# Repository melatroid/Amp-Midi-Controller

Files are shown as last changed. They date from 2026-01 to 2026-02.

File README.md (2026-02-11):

# Amp-MIDI-Controller

Files & Flashing Tool for 2040 Zero here...
<div align="left">
  <a href="https://www.nexosoft-engineering.de/amp/index.html">Full Version & Flashing Click here...</a>
</div

Amp-MIDI-Controller is a DIY build guide plus software for a flexible control module that lets you connect any MIDI foot controller to common guitar amp models and/or other MIDI interfaces using a simple configuration.

A built-in Teach Mode allows you to quickly “learn” and map specific MIDI signals, route them to different targets, and even create chained actions (multiple commands triggered by a single footswitch press).

Why this exists

Many tube amp manufacturers do not provide a way to switch the effects loop (Send/Return) via foot control. In practice, that often forces guitarists into the classic “pedalboard dance” when switching channels and toggling the loop separately.

Amp-MIDI-Controller solves this by allowing you to logically link amp channels to the effects loop, so your MIDI foot controller can change channels and switch the loop in a coordinated, predictable way.

Expandable design

At the highest configuration level, the module can even extend an amp to support two independent effects loops, adding more flexibility for channel-based routing and setups.

Display-driven workflow

An integrated display lets you select amp models and channels and makes it easy to pair the system with virtually any MIDI foot controller.

# Key Features

1. Works with any MIDI foot controller
2. Simple configuration for amps and other MIDI devices
3. Teach Mode for learning/mapping MIDI messages
4. MIDI routing & distribution across multiple outputs

### Status
- 1.) Hardware (✅)
- 2.) Hardware Test (✅)
- 3.) Software (✅)
- 4.) 3D-Print-Body (✅)
- 5.) Payment Plattform (✅)

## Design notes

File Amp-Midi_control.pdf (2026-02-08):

# AMP-Midi-Controller

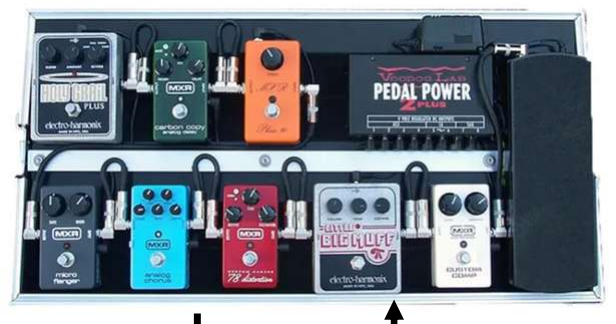
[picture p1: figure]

Works with all Amps with a real Midi Support. nexosoftengineering@gmail.com

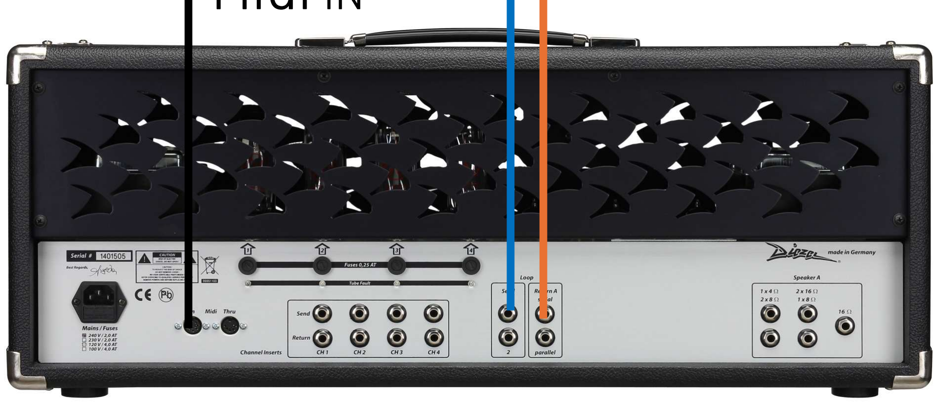
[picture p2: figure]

# Midi IN

# Midi OUT Midi IN

From FX | To FX
Send | Return

# From send To Return

Midi-maps of this amps are includet: •ENGL: • | Savage 120 Mark II • | Savage 60 Mark II • | Ironball SE
- | Powerball II • | Special Edition E670 / E670FE
- | Invader II • | Invader 150 (E646) •Diezel:• | VH4 / VH4S
- | Herbert (MK I & II) •Mesa/Boogie: • | JP-2C (John Petrucci Signature) •Hughes & Kettner: • | GrandMeister Deluxe 40
•Revv: • | Generator 120 Mark III • | D20 / D20+
•EVH: • | 5150 III (50W EL34 / Stealth) •Marshall: • | JVM410 (via MIDI Learn Mapping) •Victory:• | V4 The Kraken
•Blackstar: • | | Series One 100 / 200

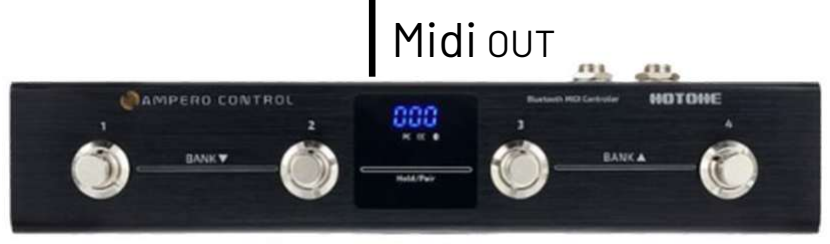
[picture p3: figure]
Midi OUT

•Modeler (Basis-Maps): • | | Fractal Audio Axe-FX III / FM9
- | Line 6 Helix Rack / Floor • | Headrush Pedalboard / Gigboard

# Hardware Parts

## LM2596 x1 Alternativ: MP1584EN

## DC Input-Jacket

## Raspberry Pi 2040 Zero x1

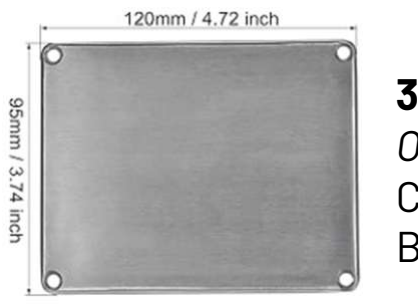
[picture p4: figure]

## 3D Print

OR

## CASE / BOX x1

## 6,35mm x4-6

## Midi 5-POL –Jacket

x2-3

SPST Momentary,
NO
x1

## SSD1306 OR SSD1315 O-LED I²C !!!

SPST Momentary,
NO
x1

# Electronic Parts

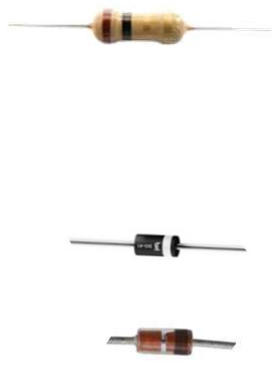
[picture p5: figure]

1N4001 x1

## 1 k Ω 0 4x

220Ω 4x

## 1 MΩ 4x

## 4,7 kΩ 1x 47 kΩ 1x

100 nF

1N4148 x1

100 uF

### 47 uF

10-22 uF

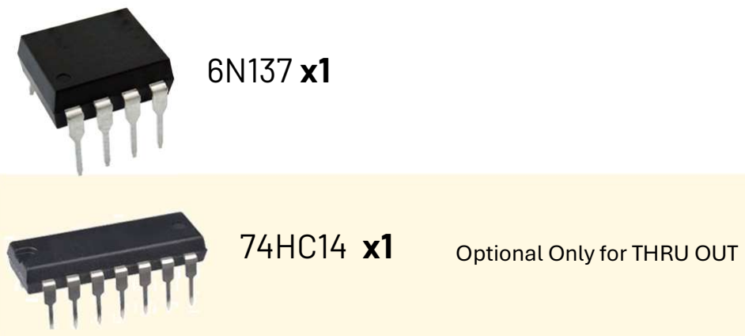
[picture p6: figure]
Optional Only for THRU OUT
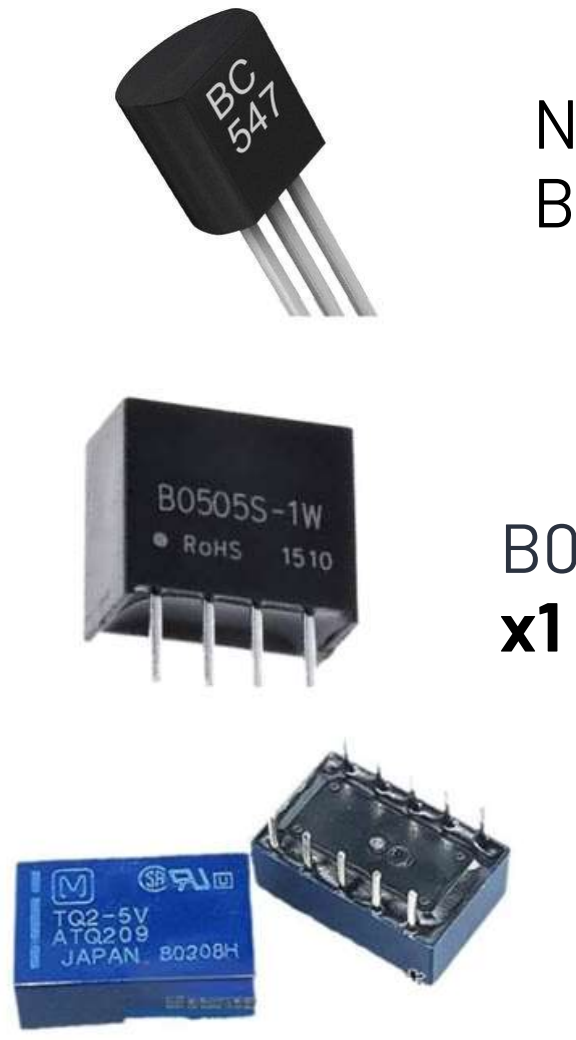
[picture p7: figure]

## NPN BC547 x3

## B0505S-1W

## TQ2-L2-5V

x1-2

## IC Socket, 8 , 14 ,10 PINS

## Electro Cookie PCB

# Tools

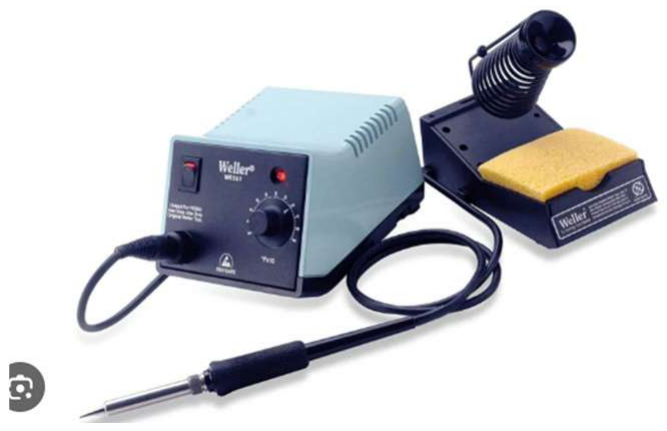
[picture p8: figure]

## Solder Station

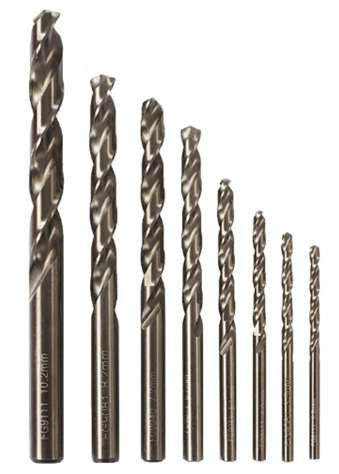
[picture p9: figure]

## Dill Set

## 3D Printer (optional)

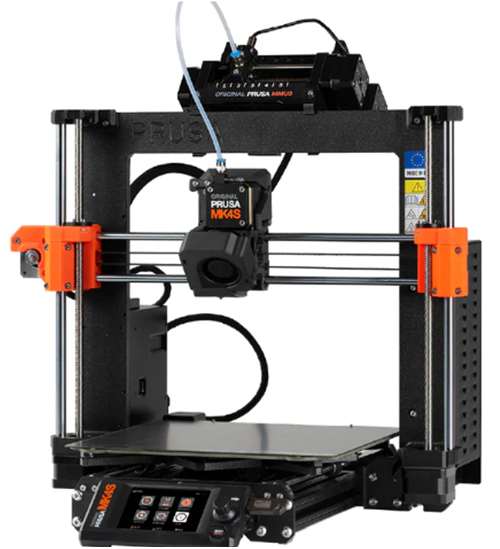
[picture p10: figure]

## Hot Glue

## Copper Tape

## EMV-Shield Inside Body

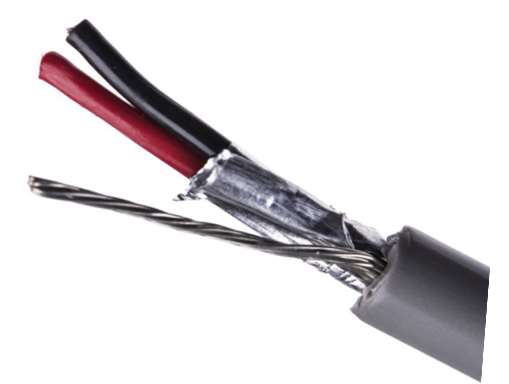
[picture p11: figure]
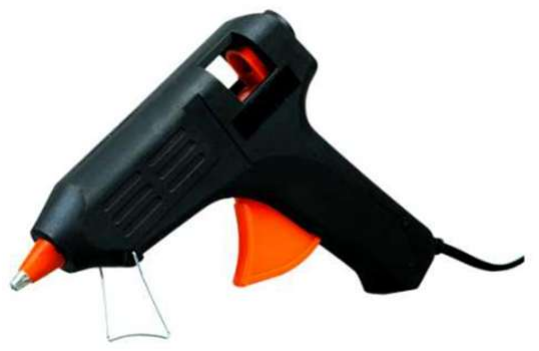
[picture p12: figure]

## Audio Wire

# Order List

# https://www.amazon.de/dp/B0D3D5YB7G

# https://www.amazon.de/dp/B0DGKQH5QF

# https://www.amazon.de/dp/B0CPSKSFZM

# https://www.amazon.de/dp/B0D3DG8M6J

# https://www.amazon.de/dp/B0DXDVL1PF

# https://www.amazon.de/dp/B0DRCSM7D1 https://www.amazon.de/dp/B0D1Q6P6WK

# https://www.amazon.de/dp/B0BN1VYW3X

# https://www.amazon.de/dp/B0BN1NKWYZ

# https://www.amazon.de/dp/B0CTM58CLJ https://www.amazon.de/dp/B08HQ7K6M7

# Body - 1 FX

# M3 x 4 x 5 mm

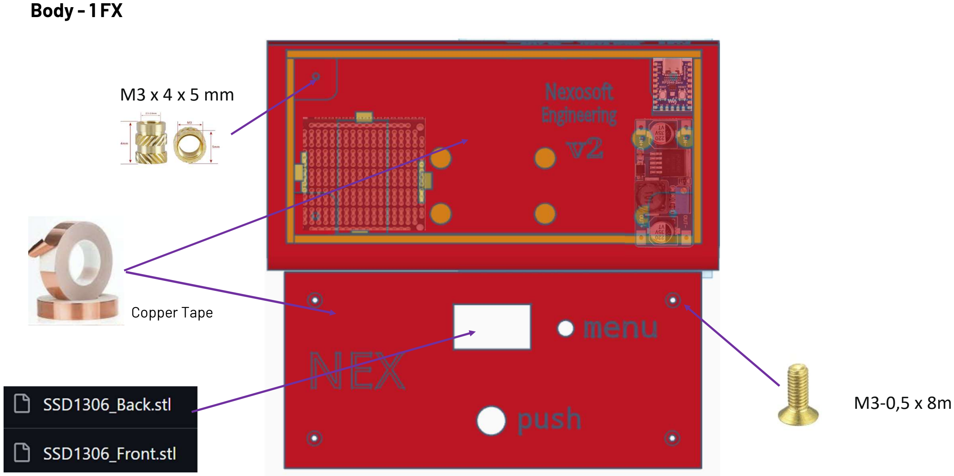
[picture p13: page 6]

# M3-0,5 x 8m

## Copper Tape

# DC/DC Converter

LM2596

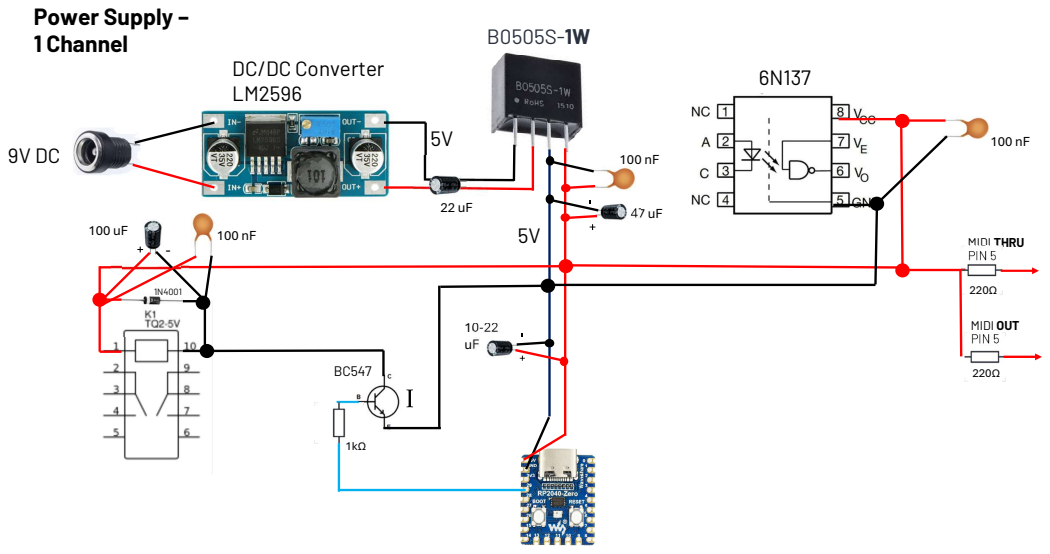
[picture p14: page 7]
Power Supply –; 1 Channel; MIDI THRU PIN 5; - MIDI OUT; PIN 5

# DC/DC Converter

LM2596

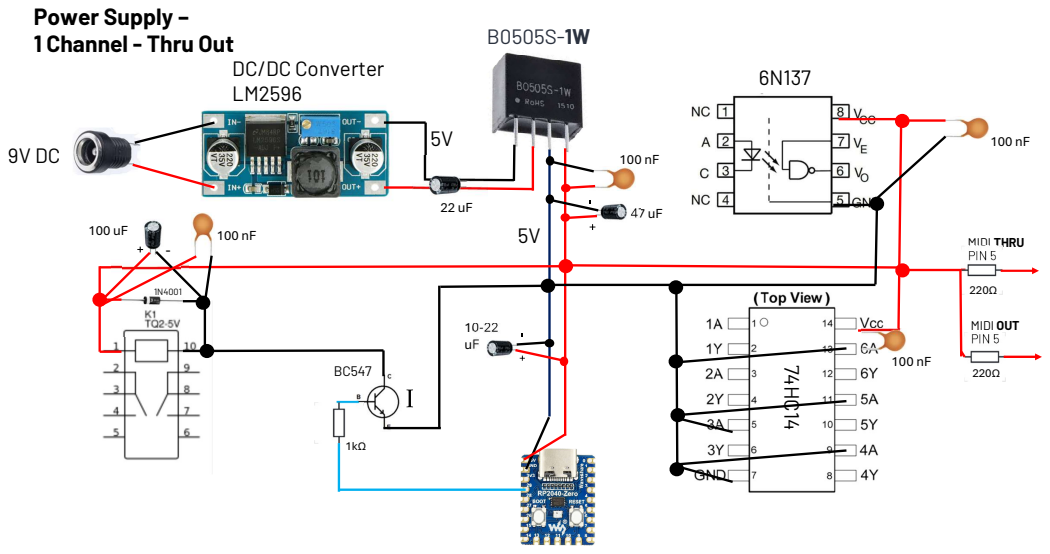
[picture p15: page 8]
Power Supply –; 1 Channel - Thru Out; MIDI THRU PIN 5; - MIDI OUT; PIN 5

# DC/DC Converter

LM2596

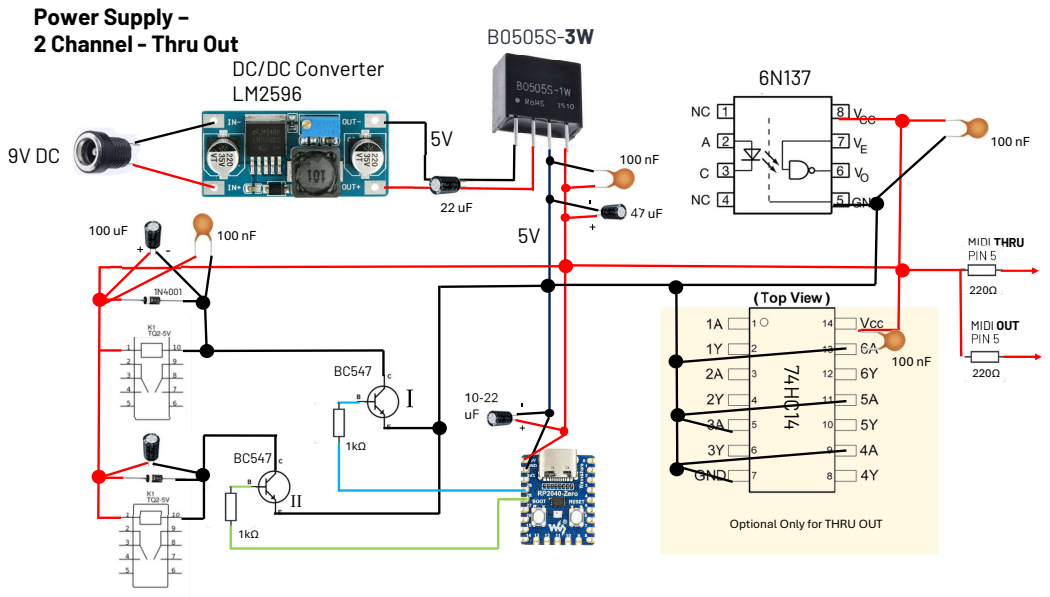
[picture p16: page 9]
Power Supply –; 2 Channel - Thru Out; MIDI THRU PIN 5; - MIDI OUT; PIN 5

Optional Only for THRU OUT

# Midi IN/OUT

# MIDI

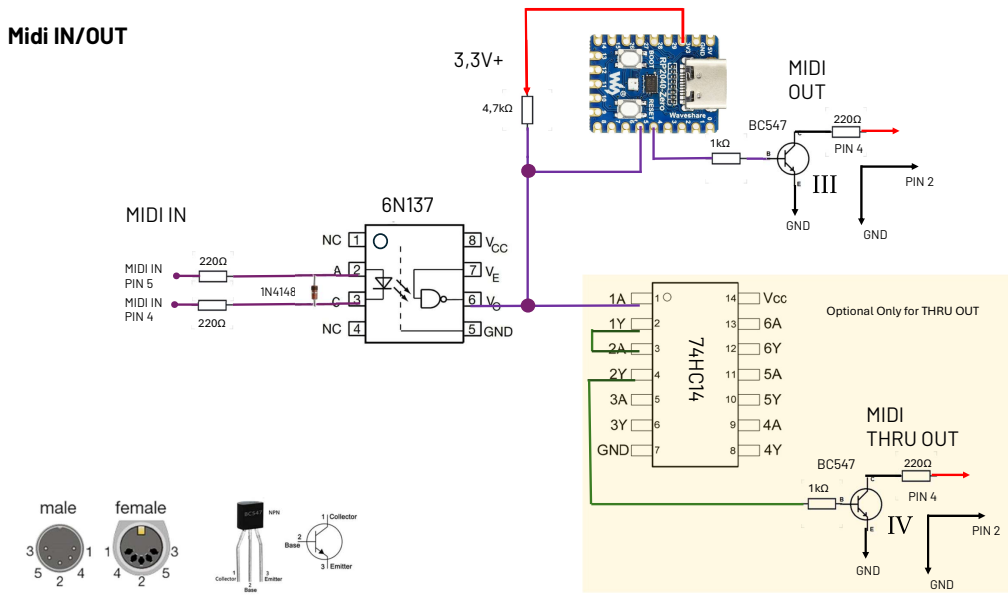
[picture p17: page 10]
MIDI IN PIN 4; MIDI IN PIN 5; PIN 4; GND; MIDI IN; MIDI; THRU OUT ⁷⁴HC14; OUT; PIN 2

Optional Only for THRU OUT

# Display

SDA

SCL

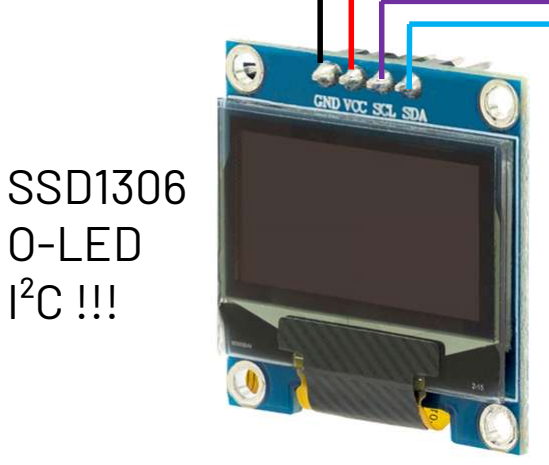
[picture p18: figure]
SSD1306 O-LED I²C !!!

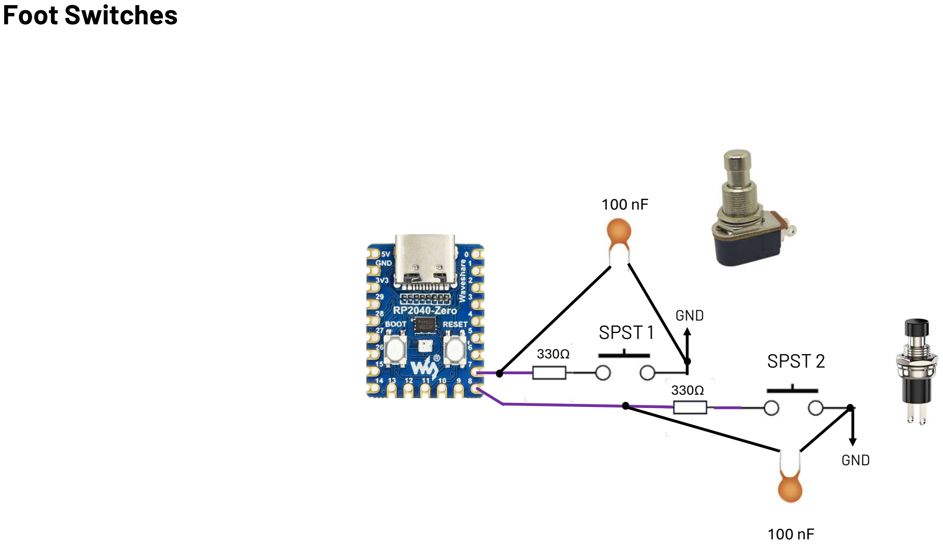
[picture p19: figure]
Foot Switches; SPST 1; SPST 2; GND

# Loop

FX

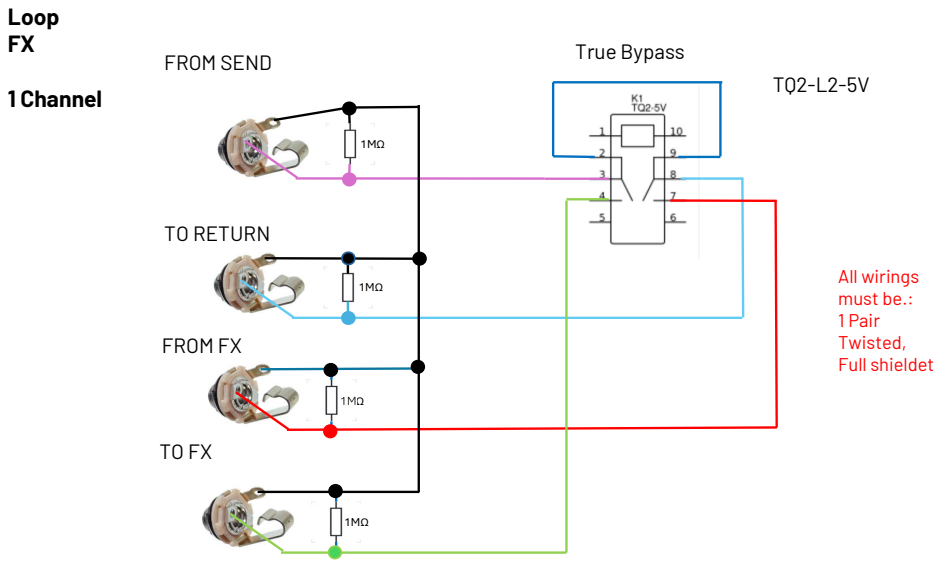
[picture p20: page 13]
1 Channel; FROM FX; FROM SEND; TO RETURN; True Bypass; All wirings must be.: 1 Pair Twisted, Full shieldet

# Loop

FX

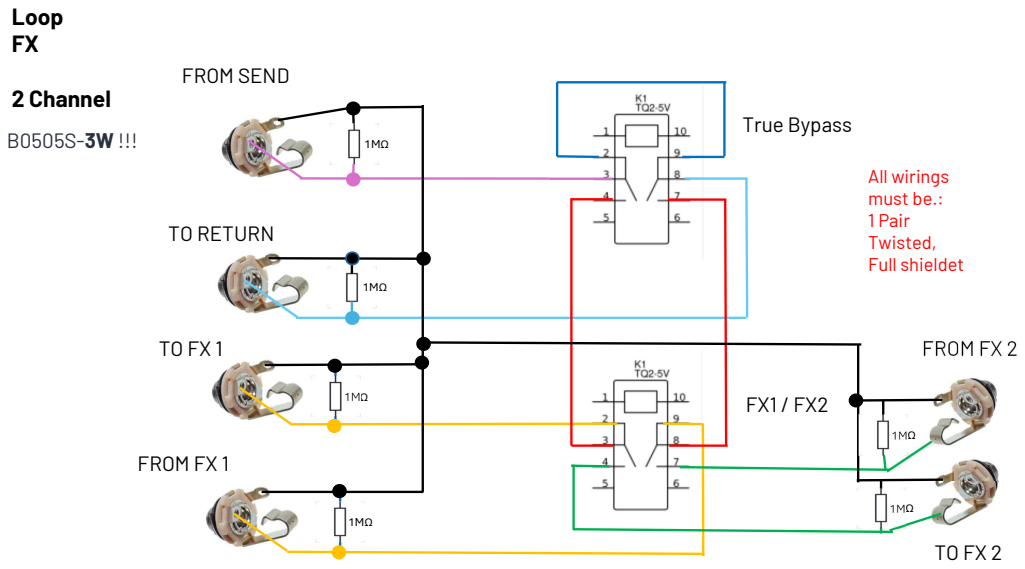
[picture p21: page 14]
2 Channel; FROM FX 1; True Bypass; TO RETURN; FROM FX 2; FROM SEND; All wirings must be.: 1 Pair Twisted, Full shieldet

# Images

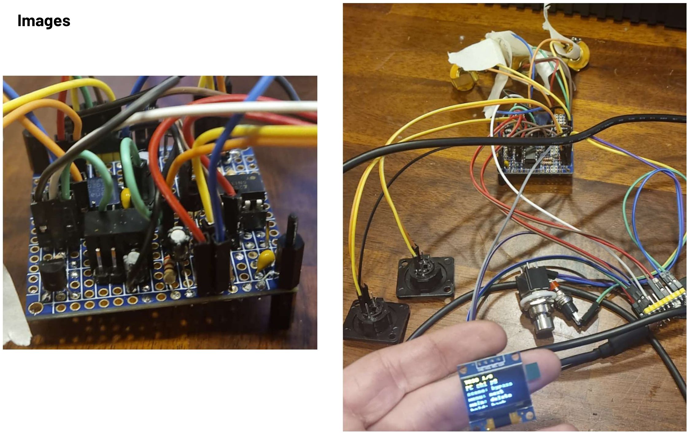
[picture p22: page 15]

# Images

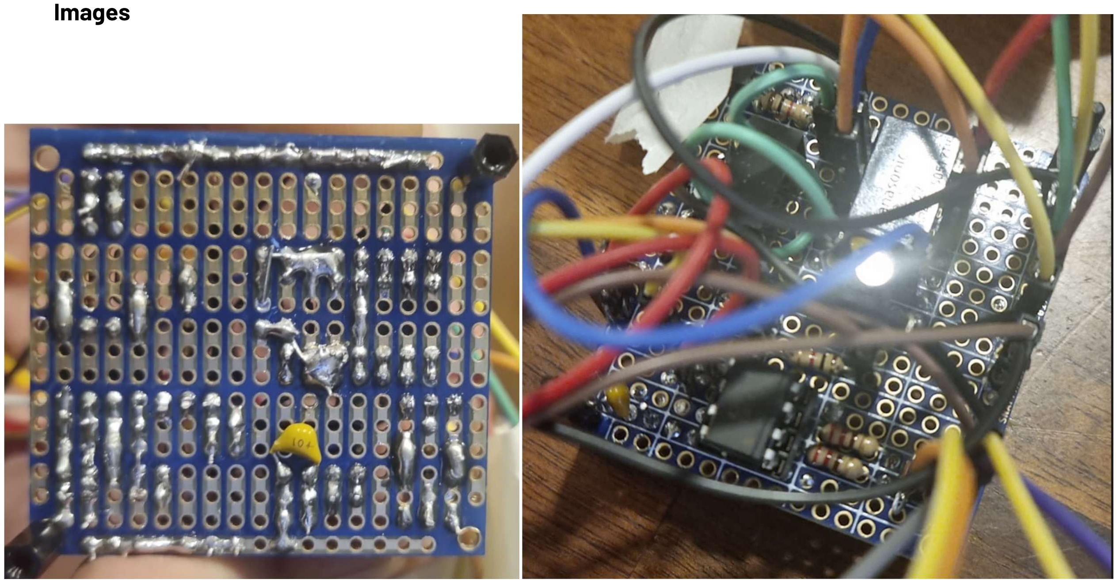
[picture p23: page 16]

# Images

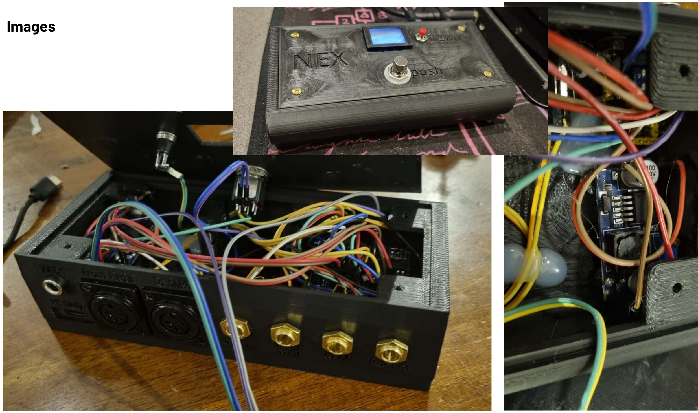
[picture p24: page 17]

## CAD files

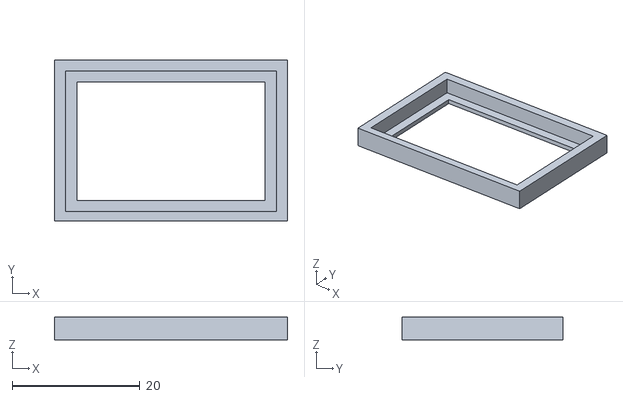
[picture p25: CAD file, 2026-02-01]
SSD1306_Front.stl
36.5 x 25.2 x 3.60

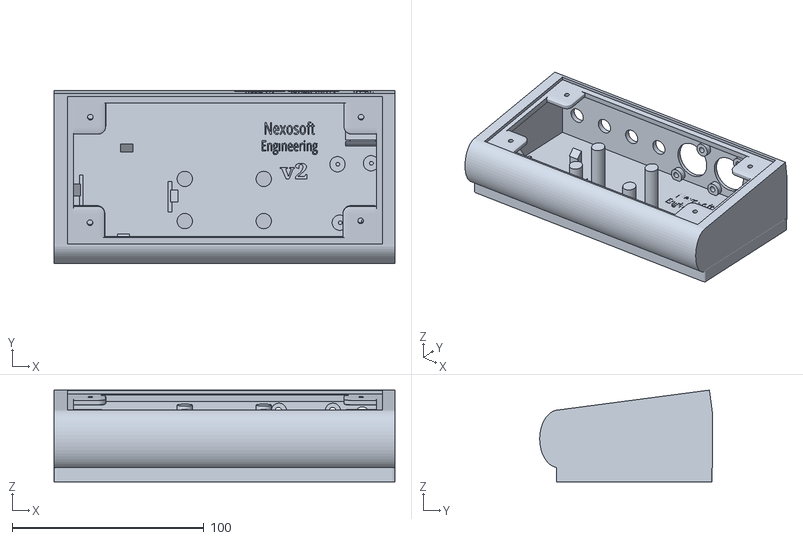
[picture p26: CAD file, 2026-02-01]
Amp Midi Switch 1 FX - FOOTS.stl
177.9 x 90.1 x 47.9

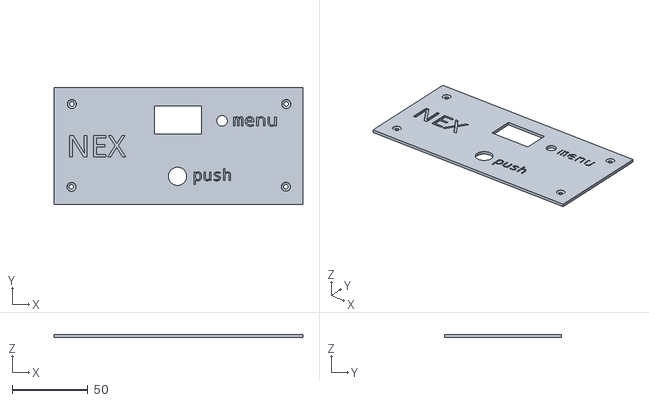
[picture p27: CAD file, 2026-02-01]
Amp Midi Switch 1 FX - TOP.stl
164.1 x 77.1 x 2.02

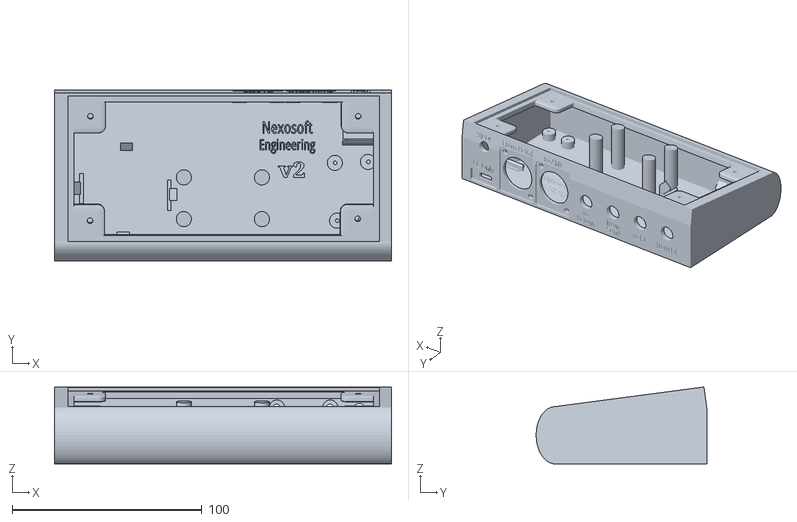
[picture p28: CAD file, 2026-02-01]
Amp Midi Switch 1 FX - DUAL LOOK.stl
177.8 x 90.1 x 40.6

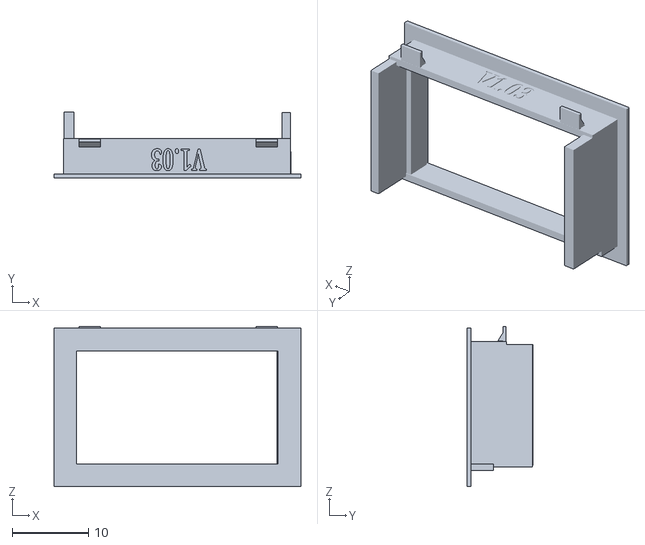
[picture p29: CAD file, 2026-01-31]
SSD1306_Back.stl
32.3 x 8.65 x 21.0

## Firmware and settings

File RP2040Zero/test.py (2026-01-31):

from machine import Pin, UART, I2C
import time
from ssd1306 import SSD1306

# ---------- Pins ----------
PIN_RELAY     = 29
PIN_RELAY2    = 28
PIN_BTN_MAIN  = 7
PIN_BTN_MENU  = 8
MIDI_IN_PIN   = 5
MIDI_OUT_PIN  = 4

DEBOUNCE_MS = 30

# ---------- OLED (SSD1306/SSD1315) ----------
OLED_SDA = 0
OLED_SCL = 1
OLED_WIDTH = 128
OLED_HEIGHT = 64
OLED_ADDR = 0x3C
OLED_UPDATE_MS = 250

oled = None
last_oled_update = time.ticks_ms()

def oled_init():
    """OLED initialisieren und kurzen Test anzeigen."""
    i2c = I2C(0, sda=Pin(OLED_SDA), scl=Pin(OLED_SCL), freq=400000)
    display = SSD1306(OLED_WIDTH, OLED_HEIGHT, i2c, addr=OLED_ADDR)
    display.fill(0)
    display.text("OLED TEST", 0, 0, 1)
    display.text("SSD1306 OK", 0, 12, 1)
    display.rect(0, 28, 127, 35, 1)
    display.text("AMP TEST", 20, 40, 1)
    display.show()
    return display

def oled_update(display, relay_on, relay2_on, main_pressed, menu_pressed):
    """Kurzer Status-Screen, um OLED im Lauf zu testen."""
    display.fill(0)
    display.text("OLED STATUS", 0, 0, 1)
    display.text("Relay1: %s" % ("ON" if relay_on else "OFF"), 0, 12, 1)
    display.text("Relay2: %s" % ("ON" if relay2_on else "OFF"), 0, 24, 1)
    display.text("Main : %s" % ("DOWN" if main_pressed else "UP"), 0, 36, 1)
    display.text("Menu : %s" % ("DOWN" if menu_pressed else "UP"), 0, 48, 1)
    display.show()

# ---------- Relais & Taster ----------
relay = Pin(PIN_RELAY, Pin.OUT, value=0)
relay2 = Pin(PIN_RELAY2, Pin.OUT, value=0)

# Relais-Zustände in Variablen halten
relay_state = 0
relay.value(relay_state)

relay2_state = 0
relay2.value(relay2_state)

btn_main = Pin(PIN_BTN_MAIN, Pin.IN, Pin.PULL_UP)
btn_menu = Pin(PIN_BTN_MENU, Pin.IN, Pin.PULL_UP)

last_main_change  = time.ticks_ms()
last_menu_change  = time.ticks_ms()
prev_main = btn_main.value()
prev_menu = btn_menu.value()
main_pressed = False
menu_pressed = False

# ---------- MIDI UART ----------
uart = UART(
    1,
    baudrate=31250,
    bits=8,
    parity=None,
    stop=1,
    tx=Pin(MIDI_OUT_PIN),
    rx=Pin(MIDI_IN_PIN),
    invert=UART.INV_TX,   # <<< TX wird invertiert
)

# ---------- MIDI-Parser ----------

class MidiParser:
    def __init__(self):
        self.running_status = None
        self.data_bytes_needed = 0
        self.data_buffer = []

    def _msg_type_and_len(self, status):
        st = status & 0xF0
        if st == 0x80: return "Note OFF", 2
        if st == 0x90: return "Note ON", 2
        if st == 0xA0: return "Poly Aftertouch", 2
        if st == 0xB0: return "Control Change", 2
        if st == 0xC0: return "Program Change", 1
        if st == 0xD0: return "Channel Aftertouch", 1
        if st == 0xE0: return "Pitch Bend", 2
        return None, 0

    def feed(self, byte):
        """Ein einzelnes MIDI-Byte verarbeiten."""
        # Realtime-Messages: immer durchlassen, Running Status bleibt gültig
        if 0xF8 <= byte <= 0xFF:
            return

        # Status-Byte
        if byte & 0x80:
            if byte >= 0xF0:
                # System Common / SysEx – hier nur verwerfen
                self.running_status = None
                self.data_bytes_needed = 0
                self.data_buffer = []
                return

            self.running_status = byte
            self.data_buffer = []
            _, n = self._msg_type_and_len(byte)
            self.data_bytes_needed = n
            return

        # Daten-Byte
        if self.running_status is None or self.data_bytes_needed == 0:
            # Daten-Byte ohne Kontext – ignorieren
            return

        self.data_buffer.append(byte)
        if len(self.data_buffer) >= self.data_bytes_needed:
            self._emit_message()
            self.data_buffer = []

    def _emit_message(self):
        msg_name, _ = self._msg_type_and_len(self.running_status)
        if msg_name is None:
            return
        ch = (self.running_status & 0x0F) + 1
        data_str = " ".join("0x%02X" % d for d in self.data_buffer)
        print("MIDI MSG: %s, Ch %d, Data: %s" % (msg_name, ch, data_str))


parser = MidiParser()

# ---------- OLED Start ----------
try:
    oled = oled_init()
except Exception as e:
    print("OLED init fehlgeschlagen:", e)
    oled = None

# ---------- Hilfsfunktionen Relais ----------

def set_relay(state):
    """Relais1-Zustand setzen (0/1) und global speichern."""
    global relay_state
    relay_state = 1 if state else 0
    relay.value(relay_state)
    print("Relais1", "EIN" if relay_state else "AUS")

def set_relay2(state):
    """Relais2-Zustand setzen (0/1) und global speichern."""
    global relay2_state
    relay2_state = 1 if state else 0
    relay2.value(relay2_state)
    print("Relais2", "EIN" if relay2_state else "AUS")

# ---------- Main Loop ----------
print("System bereit. Warte auf MIDI...")

while True:
    now = time.ticks_ms()

    # ------- MainMomentary (btn_main): Toggle Relais1 -------

    val_main = btn_main.value()
    if val_main != prev_main:
        # Zustand hat gewechselt, Zeit merken
        last_main_change = now
        prev_main = val_main
    else:
        # Zustand stabil -> nach Debounce-Zeit auswerten
        if time.ticks_diff(now, last_main_change) > DEBOUNCE_MS:
            if val_main == 0 and not main_pressed:
                # Taster ist stabil gedrückt -> Toggle
                main_pressed = True
                set_relay(0 if relay_state else 1)

            elif val_main == 1 and main_pressed:
                # Taster losgelassen -> bereit für nächsten Toggle
                main_pressed = False

    # ------- MenuMomentary (btn_menu): Toggle Relais2 -------

    val_menu = btn_menu.value()
    if val_menu != prev_menu:
        last_menu_change = now
        prev_menu = val_menu
    else:
        if time.ticks_diff(now, last_menu_change) > DEBOUNCE_MS:
            if val_menu == 0 and not menu_pressed:
                # Taster stabil gedrückt -> Relais2 toggeln
                menu_pressed = True
                set_relay2(0 if relay2_state else 1)
            elif val_menu == 1 and menu_pressed:
                # Taster losgelassen -> bereit für nächsten Toggle
                menu_pressed = False

    # ------- MIDI einlesen & Thru -------

    n = uart.any()
    if n:
        data = uart.read(n)

        for byte in data:
            parser.feed(byte)
        uart.write(data)

    # ------- OLED Update -------
    if oled is not None and time.ticks_diff(now, last_oled_update) > OLED_UPDATE_MS:
        last_oled_update = now
        oled_update(oled, relay_state, relay2_state, main_pressed, menu_pressed)

    time.sleep_us(100)
